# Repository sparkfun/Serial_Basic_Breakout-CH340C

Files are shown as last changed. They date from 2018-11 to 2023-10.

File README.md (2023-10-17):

SparkFun Serial Basic Breakout - CH340C
========================================

SparkFun Serial Basic Breakout - CH340C (https://www.sparkfun.com/products/15096)

[*SparkFun Serial Basic Breakout - CH340C (DEV-15096)*](https://www.sparkfun.com/products/15096)

This is a CH340C based board that converts USB to Serial. We've added USB-C to
the Serial Basic line which can provide up to 1.5 Amps of power to your next
project. USB-C is also _reversable_, which means you'll never plug in a cable
wrong again. It follows the standard Arduino pin out so this can be used to program the Pro 
and Pro Mini line of Arduinos.  It can also be used as a general serial device for debugging 
(such as with a GPS module).

Board defaults to 3.3V output and 3.3V serial signals, but cutting the trace on the underside of the board and 
soldering a jumper to 5V changes the VCC pin to output 5V and changes serial comm signals to 5V.

Repository Contents
-------------------

* **/Hardware** - Eagle design files (.brd, .sch)
* **/Production** - Production panel files (.brd)

Documentation
--------------

* **[SparkFun Fritzing repo](https://github.com/sparkfun/Fritzing_Parts/blob/main/products/15096_sparkfun_serial_basic_breakout_ch340c_usb_c.fzpz)** - Fritzing diagrams for SparkFun products.
* **[How to Install CH340 Drivers](https://www.sparkfun.com/ch340)** - Drivers if you need
* **[Hookup Guide](https://learn.sparkfun.com/tutorials/serial-basic-hookup-guide)** - Basic hookup guide

License Information
-------------------

This product is _**open source**_! 

Please review the LICENSE.md file for license information. 

If you have any questions or concerns on licensing, please contact techsupport@sparkfun.com.

Distributed as-is; no warranty is given.

- Your friends at SparkFun.

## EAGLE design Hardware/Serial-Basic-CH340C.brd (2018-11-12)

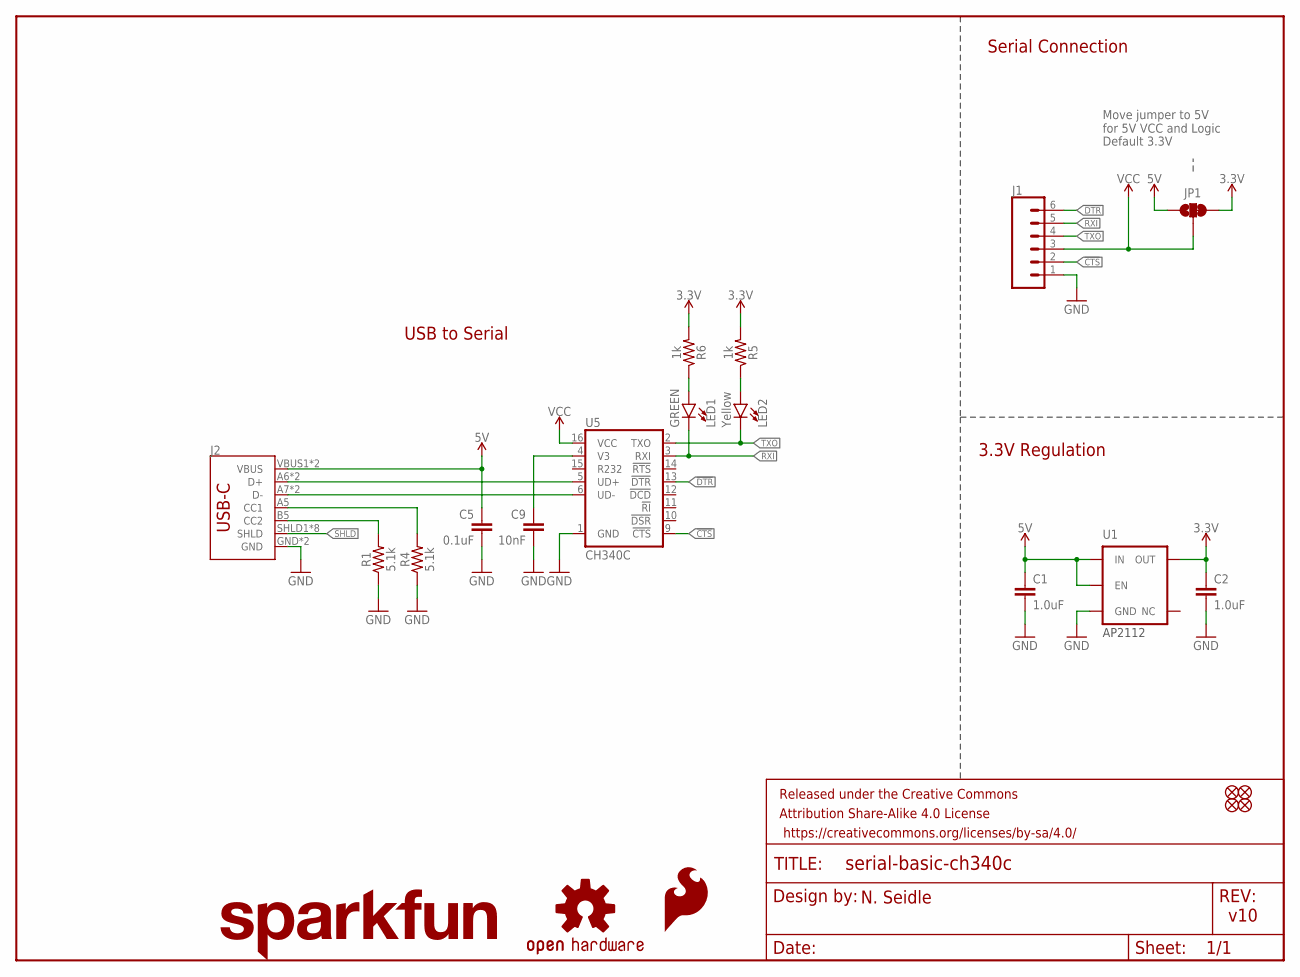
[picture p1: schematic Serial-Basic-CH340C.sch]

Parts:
C1, C2: 1.0uF; 0603
C5: 0.1uF; 0603
C9: 10nF; 0603
FRAME1: FRAME-LETTER; CREATIVE_COMMONS
J1: CONN_06SMD-FEMALE-V2; 1X06-SMD-FEMALE
J2: USB_C16PIN; USB-C-16P
JP1: JUMPER-SMT_3_1-NC_TRACE_SILK; SMT-JUMPER_3_1-NC_TRACE_SILK
JP3, JP4, JP5, JP6: FIDUCIAL1X2; FIDUCIAL-1X2
LED1: GREEN; LED-0603
LED2: Yellow; LED-0603
LOGO1: OSHW-LOGOS; OSHW-LOGO-S
LOGO2: SFE_LOGO_FLAME.1_INCH; SFE_LOGO_FLAME_.1
LOGO3: SFE_LOGO_NAME.1_INCH; SFE_LOGO_NAME_.1
R1, R4: 5.1k; 0603
R5, R6: 1k; 0603
U1: 3.3V; SOT23-5
U5: CH340C; SO016

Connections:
3.3V: C2.1, JP1.3, R5.2, R6.2, U1.5 (OUT)
5V: C1.1, C5.1, J2.VBUS1 (VBUS), J2.VBUS2 (VBUS), JP1.1, U1.1 (IN), U1.3 (EN)
!CTS: J1.2, U5.9 (!CTS)
!DTR: J1.6, U5.13 (!DTR)
CC1: J2.A5 (CC1), R4.2
CC2: J2.B5 (CC2), R1.2
D+: J2.A6 (D+), J2.B6 (D+), U5.5 (UD+)
D-: J2.A7 (D-), J2.B7 (D-), U5.6 (UD-)
GND: C1.2, C2.2, C5.2, C9.2, J1.1, J2.GND, J2.GND2 (GND), R1.1, R4.1, U1.2 (GND), U5.1 (GND)
unnamed: C9.1, U5.4 (V3)
unnamed: LED1.A, R6.1
unnamed: LED2.A, R5.1
RXI: J1.5, LED1.C, U5.3 (RXI)
SHLD: J2.SHLD1 (SHLD), J2.SHLD2 (SHLD), J2.SHLD3 (SHLD), J2.SHLD4 (SHLD), J2.SHLD5 (SHLD), J2.SHLD6 (SHLD), J2.SHLD7 (SHLD), J2.SHLD8 (SHLD)
TXO: J1.4, LED2.C, U5.2 (TXO)
VCC: J1.3, JP1.2, U5.16 (VCC)

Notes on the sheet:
Default 3.3V
v10
USB to Serial
3.3V Regulation
N. Seidle
Move jumper to 5V for 5V VCC and Logic
Serial Connection
AP2112

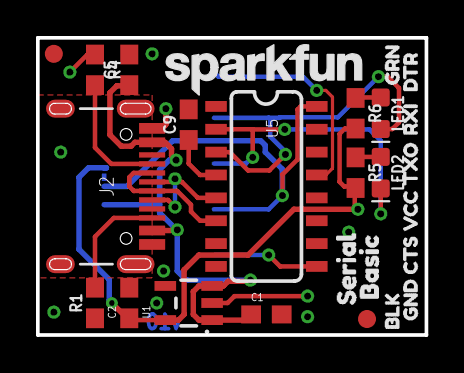
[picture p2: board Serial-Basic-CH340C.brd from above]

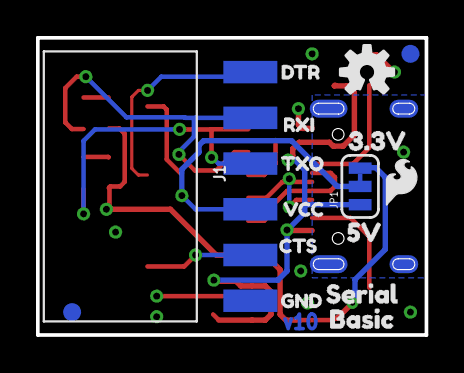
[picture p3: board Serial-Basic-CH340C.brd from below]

Board: 2 copper layers, 21.6 x 16.5 mm, 43 parts (16 on the bottom side), 16 nets.

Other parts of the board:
U$1, U$14: CTS1
U$2: 3#3V8
U$3: 5V9
U$4, U$9: SERIAL0
U$5, U$12: TXO0
U$6, U$13: VCC2
U$7, U$11: BASIC1
U$8, U$18: DTR0
U$10, U$21: RXI1
U$15, U$19: GND5
U$17: BLK6
U$20: GRN7

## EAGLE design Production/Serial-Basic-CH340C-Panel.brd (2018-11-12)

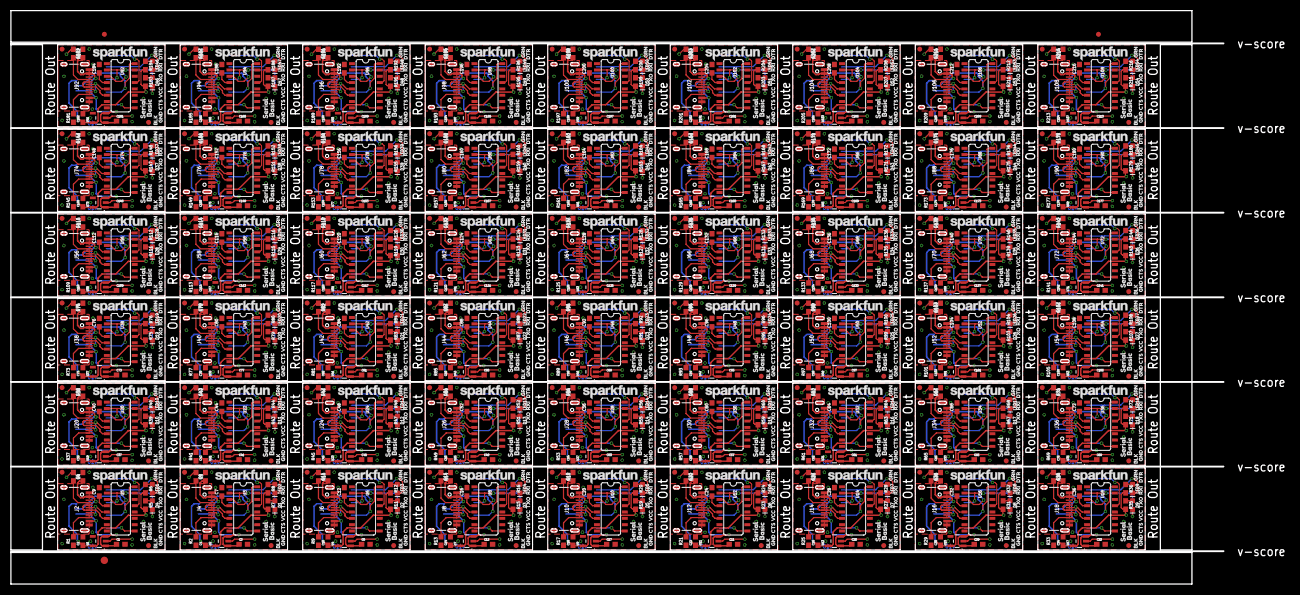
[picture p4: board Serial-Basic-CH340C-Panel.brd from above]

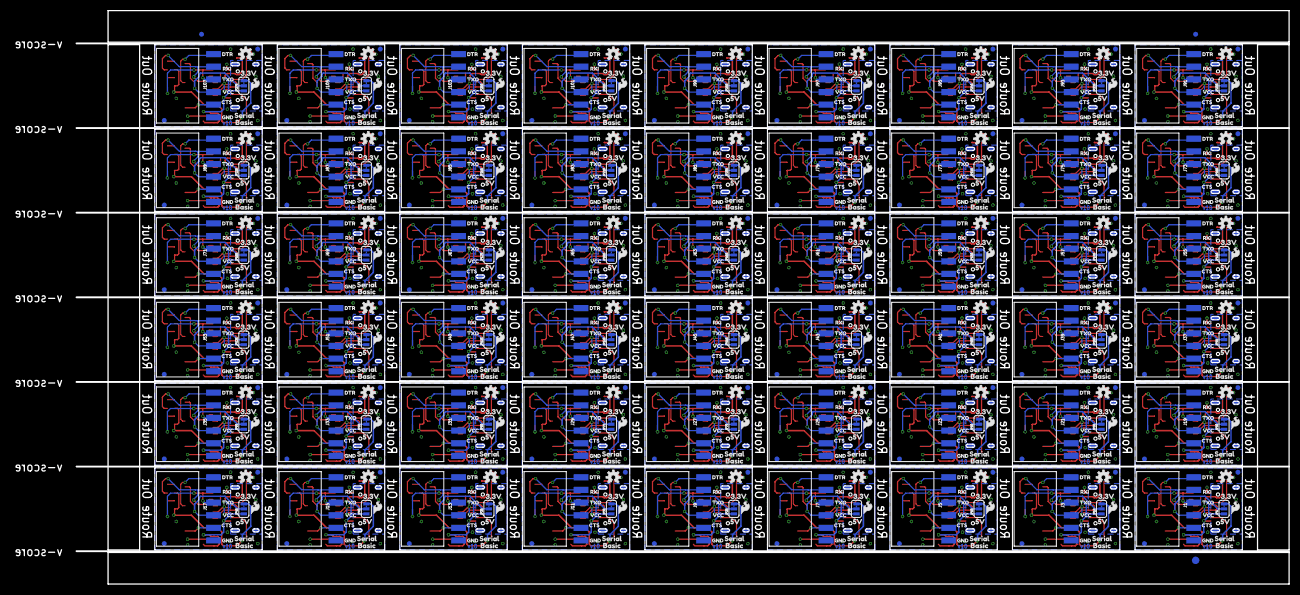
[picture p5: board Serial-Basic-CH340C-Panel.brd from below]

Board: 2 copper layers, 243.8 x 115.3 mm, 2274 parts (867 on the bottom side), 864 nets.

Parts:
C1, C2, C3, C4, C8, C10, C13, C14, C17, C18, C21, C22, C25, C26, C29, C30, C33, C34, C37, C38, C41, C42, C45, C46, C49, C50, C53, C54, C57, C58, C61, C62, C65, C66, C69, C70, C73, C74, C77, C78, C81, C82, C85, C86, C89, C90, C93, C94, C97, C98, C101, C102, C105, C106, C109, C110, C113, C114, C117, C118, C121, C122, C125, C126, C129, C130, C133, C134, C137, C138, C141, C142, C145, C146, C149, C150, C153, C154, C157, C158, C161, C162, C165, C166, C169, C170, C173, C174, C177, C178, C181, C182, C185, C186, C189, C190, C193, C194, C197, C198, C201, C202, C205, C206, C209, C210, C213, C214: 1.0uF; 0603
C5, C6, C11, C15, C19, C23, C27, C31, C35, C39, C43, C47, C51, C55, C59, C63, C67, C71, C75, C79, C83, C87, C91, C95, C99, C103, C107, C111, C115, C119, C123, C127, C131, C135, C139, C143, C147, C151, C155, C159, C163, C167, C171, C175, C179, C183, C187, C191, C195, C199, C203, C207, C211, C215: 0.1uF; 0603
C7, C9, C12, C16, C20, C24, C28, C32, C36, C40, C44, C48, C52, C56, C60, C64, C68, C72, C76, C80, C84, C88, C92, C96, C100, C104, C108, C112, C116, C120, C124, C128, C132, C136, C140, C144, C148, C152, C156, C160, C164, C168, C172, C176, C180, C184, C188, C192, C196, C200, C204, C208, C212, C216: 10nF; 0603
D1, D2, D3, D4, D5, D6, D7, D8, D9, D10, D11, D12, D13, D14, D15, D16, D17, D18, D19, D20, D21, D22, D23, D24, D25, D26, D27, D28, D29, D30, D31, D32, D33, D34, D35, D36, D37, D38, D39, D40, D41, D42, D43, D44, D45, D46, D47, D48, D49, D50, D51, D52, D53, D54: Yellow; LED-0603
E$1, E$2, E$3, E$4: FIDUCIAL-1X2
E$5, E$6: FIDUCIAL-1.5X3
J1, J3, J5, J7, J9, J11, J13, J15, J17, J19, J21, J23, J25, J27, J29, J31, J33, J35, J37, J39, J41, J43, J45, J47, J49, J51, J53, J55, J57, J59, J61, J63, J65, J67, J69, J71, J73, J75, J77, J79, J81, J83, J85, J87, J89, J91, J93, J95, J97, J99, J101, J103, J105, J107: 1X06-SMD-FEMALE
J2, J4, J6, J8, J10, J12, J14, J16, J18, J20, J22, J24, J26, J28, J30, J32, J34, J36, J38, J40, J42, J44, J46, J48, J50, J52, J54, J56, J58, J60, J62, J64, J66, J68, J70, J72, J74, J76, J78, J80, J82, J84, J86, J88, J90, J92, J94, J96, J98, J100, J102, J104, J106, J108: USB-C-16P
JP1, JP10, JP15, JP20, JP25, JP30, JP35, JP40, JP45, JP50, JP55, JP60, JP65, JP70, JP75, JP80, JP85, JP90, JP95, JP100, JP105, JP110, JP115, JP120, JP125, JP130, JP135, JP140, JP145, JP150, JP155, JP160, JP165, JP170, JP175, JP180, JP185, JP190, JP195, JP200, JP205, JP210, JP215, JP220, JP225, JP230, JP235, JP240, JP245, JP250, JP255, JP260, JP265, JP270: SMT-JUMPER_3_1-NC_TRACE_SILK
JP2, JP3, JP4, JP5, JP6, JP7, JP8, JP9, JP11, JP12, JP13, JP14, JP16, JP17, JP18, JP19, JP21, JP22, JP23, JP24, JP26, JP27, JP28, JP29, JP31, JP32, JP33, JP34, JP36, JP37, JP38, JP39, JP41, JP42, JP43, JP44, JP46, JP47, JP48, JP49, JP51, JP52, JP53, JP54, JP56, JP57, JP58, JP59, JP61, JP62, JP63, JP64, JP66, JP67, JP68, JP69, JP71, JP72, JP73, JP74, JP76, JP77, JP78, JP79, JP81, JP82, JP83, JP84, JP86, JP87, JP88, JP89, JP91, JP92, JP93, JP94, JP96, JP97, JP98, JP99, JP101, JP102, JP103, JP104, JP106, JP107, JP108, JP109, JP111, JP112, JP113, JP114, JP116, JP117, JP118, JP119, JP121, JP122, JP123, JP124, JP126, JP127, JP128, JP129, JP131, JP132, JP133, JP134, JP136, JP137, JP138, JP139, JP141, JP142, JP143, JP144, JP146, JP147, JP148, JP149, JP151, JP152, JP153, JP154, JP156, JP157, JP158, JP159, JP161, JP162, JP163, JP164, JP166, JP167, JP168, JP169, JP171, JP172, JP173, JP174, JP176, JP177, JP178, JP179, JP181, JP182, JP183, JP184, JP186, JP187, JP188, JP189, JP191, JP192, JP193, JP194, JP196, JP197, JP198, JP199, JP201, JP202, JP203, JP204, JP206, JP207, JP208, JP209, JP211, JP212, JP213, JP214, JP216, JP217, JP218, JP219, JP221, JP222, JP223, JP224, JP226, JP227, JP228, JP229, JP231, JP232, JP233, JP234, JP236, JP237, JP238, JP239, JP241, JP242, JP243, JP244, JP246, JP247, JP248, JP249, JP251, JP252, JP253, JP254, JP256, JP257, JP258, JP259, JP261, JP262, JP263, JP264, JP266, JP267, JP268, JP269: FIDUCIAL1X2; FIDUCIAL-1X2
LED1, LED2, LED3, LED4, LED5, LED6, LED7, LED8, LED9, LED10, LED11, LED12, LED13, LED14, LED15, LED16, LED17, LED18, LED19, LED20, LED21, LED22, LED23, LED24, LED25, LED26, LED27, LED28, LED29, LED30, LED31, LED32, LED33, LED34, LED35, LED36, LED37, LED38, LED39, LED40, LED41, LED42, LED43, LED44, LED45, LED46, LED47, LED48, LED49, LED50, LED51, LED52, LED53, LED54: GREEN; LED-0603
LOGO1, LOGO4, LOGO7, LOGO10, LOGO13, LOGO16, LOGO19, LOGO22, LOGO25, LOGO28, LOGO31, LOGO34, LOGO37, LOGO40, LOGO43, LOGO46, LOGO49, LOGO52, LOGO55, LOGO58, LOGO61, LOGO64, LOGO67, LOGO70, LOGO73, LOGO76, LOGO79, LOGO82, LOGO85, LOGO88, LOGO91, LOGO94, LOGO97, LOGO100, LOGO103, LOGO106, LOGO109, LOGO112, LOGO115, LOGO118, LOGO121, LOGO124, LOGO127, LOGO130, LOGO133, LOGO136, LOGO139, LOGO142, LOGO145, LOGO148, LOGO151, LOGO154, LOGO157, LOGO160: OSHW-LOGOS; OSHW-LOGO-S
LOGO2, LOGO5, LOGO8, LOGO11, LOGO14, LOGO17, LOGO20, LOGO23, LOGO26, LOGO29, LOGO32, LOGO35, LOGO38, LOGO41, LOGO44, LOGO47, LOGO50, LOGO53, LOGO56, LOGO59, LOGO62, LOGO65, LOGO68, LOGO71, LOGO74, LOGO77, LOGO80, LOGO83, LOGO86, LOGO89, LOGO92, LOGO95, LOGO98, LOGO101, LOGO104, LOGO107, LOGO110, LOGO113, LOGO116, LOGO119, LOGO122, LOGO125, LOGO128, LOGO131, LOGO134, LOGO137, LOGO140, LOGO143, LOGO146, LOGO149, LOGO152, LOGO155, LOGO158, LOGO161: SFE_LOGO_FLAME.1_INCH; SFE_LOGO_FLAME_.1
LOGO3, LOGO6, LOGO9, LOGO12, LOGO15, LOGO18, LOGO21, LOGO24, LOGO27, LOGO30, LOGO33, LOGO36, LOGO39, LOGO42, LOGO45, LOGO48, LOGO51, LOGO54, LOGO57, LOGO60, LOGO63, LOGO66, LOGO69, LOGO72, LOGO75, LOGO78, LOGO81, LOGO84, LOGO87, LOGO90, LOGO93, LOGO96, LOGO99, LOGO102, LOGO105, LOGO108, LOGO111, LOGO114, LOGO117, LOGO120, LOGO123, LOGO126, LOGO129, LOGO132, LOGO135, LOGO138, LOGO141, LOGO144, LOGO147, LOGO150, LOGO153, LOGO156, LOGO159, LOGO162: SFE_LOGO_NAME.1_INCH; SFE_LOGO_NAME_.1
R1, R2, R3, R4, R9, R10, R13, R14, R17, R18, R21, R22, R25, R26, R29, R30, R33, R34, R37, R38, R41, R42, R45, R46, R49, R50, R53, R54, R57, R58, R61, R62, R65, R66, R69, R70, R73, R74, R77, R78, R81, R82, R85, R86, R89, R90, R93, R94, R97, R98, R101, R102, R105, R106, R109, R110, R113, R114, R117, R118, R121, R122, R125, R126, R129, R130, R133, R134, R137, R138, R141, R142, R145, R146, R149, R150, R153, R154, R157, R158, R161, R162, R165, R166, R169, R170, R173, R174, R177, R178, R181, R182, R185, R186, R189, R190, R193, R194, R197, R198, R201, R202, R205, R206, R209, R210, R213, R214: 5.1k; 0603
R5, R6, R7, R8, R11, R12, R15, R16, R19, R20, R23, R24, R27, R28, R31, R32, R35, R36, R39, R40, R43, R44, R47, R48, R51, R52, R55, R56, R59, R60, R63, R64, R67, R68, R71, R72, R75, R76, R79, R80, R83, R84, R87, R88, R91, R92, R95, R96, R99, R100, R103, R104, R107, R108, R111, R112, R115, R116, R119, R120, R123, R124, R127, R128, R131, R132, R135, R136, R139, R140, R143, R144, R147, R148, R151, R152, R155, R156, R159, R160, R163, R164, R167, R168, R171, R172, R175, R176, R179, R180, R183, R184, R187, R188, R191, R192, R195, R196, R199, R200, R203, R204, R207, R208, R211, R212, R215, R216: 1k; 0603
U1, U2, U4, U7, U9, U11, U13, U15, U17, U19, U21, U23, U25, U27, U29, U31, U33, U35, U37, U39, U41, U43, U45, U47, U49, U51, U53, U55, U57, U59, U61, U63, U65, U67, U69, U71, U73, U75, U77, U79, U81, U83, U85, U87, U89, U91, U93, U95, U97, U99, U101, U103, U105, U107: AP2112-3.3V; SOT23-5
U3, U5, U6, U8, U10, U12, U14, U16, U18, U20, U22, U24, U26, U28, U30, U32, U34, U36, U38, U40, U42, U44, U46, U48, U50, U52, U54, U56, U58, U60, U62, U64, U66, U68, U70, U72, U74, U76, U78, U80, U82, U84, U86, U88, U90, U92, U94, U96, U98, U100, U102, U104, U106, U108: CH340C; SO016
U$1, U$14, U$28, U$37, U$48, U$57, U$68, U$77, U$88, U$97, U$108, U$117, U$128, U$137, U$148, U$157, U$168, U$177, U$188, U$197, U$208, U$217, U$228, U$237, U$248, U$257, U$268, U$277, U$288, U$297, U$308, U$317, U$328, U$337, U$348, U$357, U$368, U$377, U$388, U$397, U$408, U$417, U$428, U$437, U$448, U$457, U$468, U$477, U$488, U$497, U$508, U$517, U$528, U$537, U$548, U$557, U$568, U$577, U$588, U$597, U$608, U$617, U$628, U$637, U$648, U$657, U$668, U$677, U$688, U$697, U$708, U$717, U$728, U$737, U$748, U$757, U$768, U$777, U$788, U$797, U$808, U$817, U$828, U$837, U$848, U$857, U$868, U$877, U$888, U$897, U$908, U$917, U$928, U$937, U$948, U$957, U$968, U$977, U$988, U$997, U$1008, U$1017, U$1028, U$1037, U$1048, U$1057, U$1068, U$1077: CTS1
U$2, U$16, U$41, U$61, U$81, U$101, U$121, U$141, U$161, U$181, U$201, U$221, U$241, U$261, U$281, U$301, U$321, U$341, U$361, U$381, U$401, U$421, U$441, U$461, U$481, U$501, U$521, U$541, U$561, U$581, U$601, U$621, U$641, U$661, U$681, U$701, U$721, U$741, U$761, U$781, U$801, U$821, U$841, U$861, U$881, U$901, U$921, U$941, U$961, U$981, U$1001, U$1021, U$1041, U$1061: 3#3V8
U$3, U$22, U$42, U$62, U$82, U$102, U$122, U$142, U$162, U$182, U$202, U$222, U$242, U$262, U$282, U$302, U$322, U$342, U$362, U$382, U$402, U$422, U$442, U$462, U$482, U$502, U$522, U$542, U$562, U$582, U$602, U$622, U$642, U$662, U$682, U$702, U$722, U$742, U$762, U$782, U$802, U$822, U$842, U$862, U$882, U$902, U$922, U$942, U$962, U$982, U$1002, U$1022, U$1042, U$1062: 5V9
U$4, U$9, U$31, U$39, U$51, U$59, U$71, U$79, U$91, U$99, U$111, U$119, U$131, U$139, U$151, U$159, U$171, U$179, U$191, U$199, U$211, U$219, U$231, U$239, U$251, U$259, U$271, U$279, U$291, U$299, U$311, U$319, U$331, U$339, U$351, U$359, U$371, U$379, U$391, U$399, U$411, U$419, U$431, U$439, U$451, U$459, U$471, U$479, U$491, U$499, U$511, U$519, U$531, U$539, U$551, U$559, U$571, U$579, U$591, U$599, U$611, U$619, U$631, U$639, U$651, U$659, U$671, U$679, U$691, U$699, U$711, U$719, U$731, U$739, U$751, U$759, U$771, U$779, U$791, U$799, U$811, U$819, U$831, U$839, U$851, U$859, U$871, U$879, U$891, U$899, U$911, U$919, U$931, U$939, U$951, U$959, U$971, U$979, U$991, U$999, U$1011, U$1019, U$1031, U$1039, U$1051, U$1059, U$1071, U$1079: SERIAL0
U$5, U$12, U$29, U$35, U$49, U$55, U$69, U$75, U$89, U$95, U$109, U$115, U$129, U$135, U$149, U$155, U$169, U$175, U$189, U$195, U$209, U$215, U$229, U$235, U$249, U$255, U$269, U$275, U$289, U$295, U$309, U$315, U$329, U$335, U$349, U$355, U$369, U$375, U$389, U$395, U$409, U$415, U$429, U$435, U$449, U$455, U$469, U$475, U$489, U$495, U$509, U$515, U$529, U$535, U$549, U$555, U$569, U$575, U$589, U$595, U$609, U$615, U$629, U$635, U$649, U$655, U$669, U$675, U$689, U$695, U$709, U$715, U$729, U$735, U$749, U$755, U$769, U$775, U$789, U$795, U$809, U$815, U$829, U$835, U$849, U$855, U$869, U$875, U$889, U$895, U$909, U$915, U$929, U$935, U$949, U$955, U$969, U$975, U$989, U$995, U$1009, U$1015, U$1029, U$1035, U$1049, U$1055, U$1069, U$1075: TXO0
U$6, U$13, U$30, U$36, U$50, U$56, U$70, U$76, U$90, U$96, U$110, U$116, U$130, U$136, U$150, U$156, U$170, U$176, U$190, U$196, U$210, U$216, U$230, U$236, U$250, U$256, U$270, U$276, U$290, U$296, U$310, U$316, U$330, U$336, U$350, U$356, U$370, U$376, U$390, U$396, U$410, U$416, U$430, U$436, U$450, U$456, U$470, U$476, U$490, U$496, U$510, U$516, U$530, U$536, U$550, U$556, U$570, U$576, U$590, U$596, U$610, U$616, U$630, U$636, U$650, U$656, U$670, U$676, U$690, U$696, U$710, U$716, U$730, U$736, U$750, U$756, U$770, U$776, U$790, U$796, U$810, U$816, U$830, U$836, U$850, U$856, U$870, U$876, U$890, U$896, U$910, U$916, U$930, U$936, U$950, U$956, U$970, U$976, U$990, U$996, U$1010, U$1016, U$1030, U$1036, U$1050, U$1056, U$1070, U$1076: VCC2
U$7, U$11, U$32, U$40, U$52, U$60, U$72, U$80, U$92, U$100, U$112, U$120, U$132, U$140, U$152, U$160, U$172, U$180, U$192, U$200, U$212, U$220, U$232, U$240, U$252, U$260, U$272, U$280, U$292, U$300, U$312, U$320, U$332, U$340, U$352, U$360, U$372, U$380, U$392, U$400, U$412, U$420, U$432, U$440, U$452, U$460, U$472, U$480, U$492, U$500, U$512, U$520, U$532, U$540, U$552, U$560, U$572, U$580, U$592, U$600, U$612, U$620, U$632, U$640, U$652, U$660, U$672, U$680, U$692, U$700, U$712, U$720, U$732, U$740, U$752, U$760, U$772, U$780, U$792, U$800, U$812, U$820, U$832, U$840, U$852, U$860, U$872, U$880, U$892, U$900, U$912, U$920, U$932, U$940, U$952, U$960, U$972, U$980, U$992, U$1000, U$1012, U$1020, U$1032, U$1040, U$1052, U$1060, U$1072, U$1080: BASIC1
U$8, U$18, U$24, U$33, U$44, U$53, U$64, U$73, U$84, U$93, U$104, U$113, U$124, U$133, U$144, U$153, U$164, U$173, U$184, U$193, U$204, U$213, U$224, U$233, U$244, U$253, U$264, U$273, U$284, U$293, U$304, U$313, U$324, U$333, U$344, U$353, U$364, U$373, U$384, U$393, U$404, U$413, U$424, U$433, U$444, U$453, U$464, U$473, U$484, U$493, U$504, U$513, U$524, U$533, U$544, U$553, U$564, U$573, U$584, U$593, U$604, U$613, U$624, U$633, U$644, U$653, U$664, U$673, U$684, U$693, U$704, U$713, U$724, U$733, U$744, U$753, U$764, U$773, U$784, U$793, U$804, U$813, U$824, U$833, U$844, U$853, U$864, U$873, U$884, U$893, U$904, U$913, U$924, U$933, U$944, U$953, U$964, U$973, U$984, U$993, U$1004, U$1013, U$1024, U$1033, U$1044, U$1053, U$1064, U$1073: DTR0
U$10, U$21, U$27, U$34, U$47, U$54, U$67, U$74, U$87, U$94, U$107, U$114, U$127, U$134, U$147, U$154, U$167, U$174, U$187, U$194, U$207, U$214, U$227, U$234, U$247, U$254, U$267, U$274, U$287, U$294, U$307, U$314, U$327, U$334, U$347, U$354, U$367, U$374, U$387, U$394, U$407, U$414, U$427, U$434, U$447, U$454, U$467, U$474, U$487, U$494, U$507, U$514, U$527, U$534, U$547, U$554, U$567, U$574, U$587, U$594, U$607, U$614, U$627, U$634, U$647, U$654, U$667, U$674, U$687, U$694, U$707, U$714, U$727, U$734, U$747, U$754, U$767, U$774, U$787, U$794, U$807, U$814, U$827, U$834, U$847, U$854, U$867, U$874, U$887, U$894, U$907, U$914, U$927, U$934, U$947, U$954, U$967, U$974, U$987, U$994, U$1007, U$1014, U$1027, U$1034, U$1047, U$1054, U$1067, U$1074: RXI1
U$15, U$19, U$25, U$38, U$45, U$58, U$65, U$78, U$85, U$98, U$105, U$118, U$125, U$138, U$145, U$158, U$165, U$178, U$185, U$198, U$205, U$218, U$225, U$238, U$245, U$258, U$265, U$278, U$285, U$298, U$305, U$318, U$325, U$338, U$345, U$358, U$365, U$378, U$385, U$398, U$405, U$418, U$425, U$438, U$445, U$458, U$465, U$478, U$485, U$498, U$505, U$518, U$525, U$538, U$545, U$558, U$565, U$578, U$585, U$598, U$605, U$618, U$625, U$638, U$645, U$658, U$665, U$678, U$685, U$698, U$705, U$718, U$725, U$738, U$745, U$758, U$765, U$778, U$785, U$798, U$805, U$818, U$825, U$838, U$845, U$858, U$865, U$878, U$885, U$898, U$905, U$918, U$925, U$938, U$945, U$958, U$965, U$978, U$985, U$998, U$1005, U$1018, U$1025, U$1038, U$1045, U$1058, U$1065, U$1078: GND5
U$17, U$23, U$43, U$63, U$83, U$103, U$123, U$143, U$163, U$183, U$203, U$223, U$243, U$263, U$283, U$303, U$323, U$343, U$363, U$383, U$403, U$423, U$443, U$463, U$483, U$503, U$523, U$543, U$563, U$583, U$603, U$623, U$643, U$663, U$683, U$703, U$723, U$743, U$763, U$783, U$803, U$823, U$843, U$863, U$883, U$903, U$923, U$943, U$963, U$983, U$1003, U$1023, U$1043, U$1063: BLK6
U$20, U$26, U$46, U$66, U$86, U$106, U$126, U$146, U$166, U$186, U$206, U$226, U$246, U$266, U$286, U$306, U$326, U$346, U$366, U$386, U$406, U$426, U$446, U$466, U$486, U$506, U$526, U$546, U$566, U$586, U$606, U$626, U$646, U$666, U$686, U$706, U$726, U$746, U$766, U$786, U$806, U$826, U$846, U$866, U$886, U$906, U$926, U$946, U$966, U$986, U$1006, U$1026, U$1046, U$1066: GRN7

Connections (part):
3.3V: C2.1, JP1.3, R5.2, R6.2, U1.5
3.3V1: C4.1, JP10.3, R7.2, R8.2, U2.5
3.3V2: C10.1, JP15.3, R11.2, R12.2, U4.5
3.3V3: C14.1, JP20.3, R15.2, R16.2, U7.5
3.3V4: C18.1, JP25.3, R19.2, R20.2, U9.5
3.3V5: C22.1, JP30.3, R23.2, R24.2, U11.5
3.3V6: C26.1, JP35.3, R27.2, R28.2, U13.5
3.3V7: C30.1, JP40.3, R31.2, R32.2, U15.5
3.3V8: C34.1, JP45.3, R35.2, R36.2, U17.5
3.3V9: C38.1, JP50.3, R39.2, R40.2, U19.5
3.3V10: C42.1, JP55.3, R43.2, R44.2, U21.5
3.3V11: C46.1, JP60.3, R47.2, R48.2, U23.5
3.3V12: C50.1, JP65.3, R51.2, R52.2, U25.5
3.3V13: C54.1, JP70.3, R55.2, R56.2, U27.5
3.3V14: C58.1, JP75.3, R59.2, R60.2, U29.5
3.3V15: C62.1, JP80.3, R63.2, R64.2, U31.5
3.3V16: C66.1, JP85.3, R67.2, R68.2, U33.5
3.3V17: C70.1, JP90.3, R71.2, R72.2, U35.5
3.3V18: C74.1, JP95.3, R75.2, R76.2, U37.5
3.3V19: C78.1, JP100.3, R79.2, R80.2, U39.5
3.3V20: C82.1, JP105.3, R83.2, R84.2, U41.5
3.3V21: C86.1, JP110.3, R87.2, R88.2, U43.5
3.3V22: C90.1, JP115.3, R91.2, R92.2, U45.5
3.3V23: C94.1, JP120.3, R95.2, R96.2, U47.5
3.3V24: C98.1, JP125.3, R99.2, R100.2, U49.5
3.3V25: C102.1, JP130.3, R103.2, R104.2, U51.5
3.3V26: C106.1, JP135.3, R107.2, R108.2, U53.5
3.3V27: C110.1, JP140.3, R111.2, R112.2, U55.5
3.3V28: C114.1, JP145.3, R115.2, R116.2, U57.5
3.3V29: C118.1, JP150.3, R119.2, R120.2, U59.5
3.3V30: C122.1, JP155.3, R123.2, R124.2, U61.5
3.3V31: C126.1, JP160.3, R127.2, R128.2, U63.5
3.3V32: C130.1, JP165.3, R131.2, R132.2, U65.5
3.3V33: C134.1, JP170.3, R135.2, R136.2, U67.5
3.3V34: C138.1, JP175.3, R139.2, R140.2, U69.5
3.3V35: C142.1, JP180.3, R143.2, R144.2, U71.5
3.3V36: C146.1, JP185.3, R147.2, R148.2, U73.5
3.3V37: C150.1, JP190.3, R151.2, R152.2, U75.5
3.3V38: C154.1, JP195.3, R155.2, R156.2, U77.5
3.3V39: C158.1, JP200.3, R159.2, R160.2, U79.5
3.3V40: C162.1, JP205.3, R163.2, R164.2, U81.5
3.3V41: C166.1, JP210.3, R167.2, R168.2, U83.5
3.3V42: C170.1, JP215.3, R171.2, R172.2, U85.5
3.3V43: C174.1, JP220.3, R175.2, R176.2, U87.5
3.3V44: C178.1, JP225.3, R179.2, R180.2, U89.5
3.3V45: C182.1, JP230.3, R183.2, R184.2, U91.5
3.3V46: C186.1, JP235.3, R187.2, R188.2, U93.5
3.3V47: C190.1, JP240.3, R191.2, R192.2, U95.5
3.3V48: C194.1, JP245.3, R195.2, R196.2, U97.5
3.3V49: C198.1, JP250.3, R199.2, R200.2, U99.5
3.3V50: C202.1, JP255.3, R203.2, R204.2, U101.5
3.3V51: C206.1, JP260.3, R207.2, R208.2, U103.5
3.3V52: C210.1, JP265.3, R211.2, R212.2, U105.5
3.3V53: C214.1, JP270.3, R215.2, R216.2, U107.5
5V: C1.1, C5.1, J2.VBUS1, J2.VBUS2, JP1.1, U1.1, U1.3
5V1: C3.1, C6.1, J4.VBUS1, J4.VBUS2, JP10.1, U2.1, U2.3
5V2: C8.1, C11.1, J6.VBUS1, J6.VBUS2, JP15.1, U4.1, U4.3
5V3: C13.1, C15.1, J8.VBUS1, J8.VBUS2, JP20.1, U7.1, U7.3
5V4: C17.1, C19.1, J10.VBUS1, J10.VBUS2, JP25.1, U9.1, U9.3
5V5: C21.1, C23.1, J12.VBUS1, J12.VBUS2, JP30.1, U11.1, U11.3
5V6: C25.1, C27.1, J14.VBUS1, J14.VBUS2, JP35.1, U13.1, U13.3
5V7: C29.1, C31.1, J16.VBUS1, J16.VBUS2, JP40.1, U15.1, U15.3
5V8: C33.1, C35.1, J18.VBUS1, J18.VBUS2, JP45.1, U17.1, U17.3
5V9: C37.1, C39.1, J20.VBUS1, J20.VBUS2, JP50.1, U19.1, U19.3
5V10: C41.1, C43.1, J22.VBUS1, J22.VBUS2, JP55.1, U21.1, U21.3
5V11: C45.1, C47.1, J24.VBUS1, J24.VBUS2, JP60.1, U23.1, U23.3
5V12: C49.1, C51.1, J26.VBUS1, J26.VBUS2, JP65.1, U25.1, U25.3
5V13: C53.1, C55.1, J28.VBUS1, J28.VBUS2, JP70.1, U27.1, U27.3
5V14: C57.1, C59.1, J30.VBUS1, J30.VBUS2, JP75.1, U29.1, U29.3
5V15: C61.1, C63.1, J32.VBUS1, J32.VBUS2, JP80.1, U31.1, U31.3
5V16: C65.1, C67.1, J34.VBUS1, J34.VBUS2, JP85.1, U33.1, U33.3
5V17: C69.1, C71.1, J36.VBUS1, J36.VBUS2, JP90.1, U35.1, U35.3
5V18: C73.1, C75.1, J38.VBUS1, J38.VBUS2, JP95.1, U37.1, U37.3
5V19: C77.1, C79.1, J40.VBUS1, J40.VBUS2, JP100.1, U39.1, U39.3
5V20: C81.1, C83.1, J42.VBUS1, J42.VBUS2, JP105.1, U41.1, U41.3
5V21: C85.1, C87.1, J44.VBUS1, J44.VBUS2, JP110.1, U43.1, U43.3
5V22: C89.1, C91.1, J46.VBUS1, J46.VBUS2, JP115.1, U45.1, U45.3
5V23: C93.1, C95.1, J48.VBUS1, J48.VBUS2, JP120.1, U47.1, U47.3
5V24: C97.1, C99.1, J50.VBUS1, J50.VBUS2, JP125.1, U49.1, U49.3
5V25: C101.1, C103.1, J52.VBUS1, J52.VBUS2, JP130.1, U51.1, U51.3
5V26: C105.1, C107.1, J54.VBUS1, J54.VBUS2, JP135.1, U53.1, U53.3
5V27: C109.1, C111.1, J56.VBUS1, J56.VBUS2, JP140.1, U55.1, U55.3
5V28: C113.1, C115.1, J58.VBUS1, J58.VBUS2, JP145.1, U57.1, U57.3
5V29: C117.1, C119.1, J60.VBUS1, J60.VBUS2, JP150.1, U59.1, U59.3
5V30: C121.1, C123.1, J62.VBUS1, J62.VBUS2, JP155.1, U61.1, U61.3
5V31: C125.1, C127.1, J64.VBUS1, J64.VBUS2, JP160.1, U63.1, U63.3
5V32: C129.1, C131.1, J66.VBUS1, J66.VBUS2, JP165.1, U65.1, U65.3
5V33: C133.1, C135.1, J68.VBUS1, J68.VBUS2, JP170.1, U67.1, U67.3
5V34: C137.1, C139.1, J70.VBUS1, J70.VBUS2, JP175.1, U69.1, U69.3
5V35: C141.1, C143.1, J72.VBUS1, J72.VBUS2, JP180.1, U71.1, U71.3
5V36: C145.1, C147.1, J74.VBUS1, J74.VBUS2, JP185.1, U73.1, U73.3
5V37: C149.1, C151.1, J76.VBUS1, J76.VBUS2, JP190.1, U75.1, U75.3
5V38: C153.1, C155.1, J78.VBUS1, J78.VBUS2, JP195.1, U77.1, U77.3
5V39: C157.1, C159.1, J80.VBUS1, J80.VBUS2, JP200.1, U79.1, U79.3
5V40: C161.1, C163.1, J82.VBUS1, J82.VBUS2, JP205.1, U81.1, U81.3
5V41: C165.1, C167.1, J84.VBUS1, J84.VBUS2, JP210.1, U83.1, U83.3
5V42: C169.1, C171.1, J86.VBUS1, J86.VBUS2, JP215.1, U85.1, U85.3
5V43: C173.1, C175.1, J88.VBUS1, J88.VBUS2, JP220.1, U87.1, U87.3
5V44: C177.1, C179.1, J90.VBUS1, J90.VBUS2, JP225.1, U89.1, U89.3
5V45: C181.1, C183.1, J92.VBUS1, J92.VBUS2, JP230.1, U91.1, U91.3
5V46: C185.1, C187.1, J94.VBUS1, J94.VBUS2, JP235.1, U93.1, U93.3
5V47: C189.1, C191.1, J96.VBUS1, J96.VBUS2, JP240.1, U95.1, U95.3
5V48: C193.1, C195.1, J98.VBUS1, J98.VBUS2, JP245.1, U97.1, U97.3
5V49: C197.1, C199.1, J100.VBUS1, J100.VBUS2, JP250.1, U99.1, U99.3
5V50: C201.1, C203.1, J102.VBUS1, J102.VBUS2, JP255.1, U101.1, U101.3
5V51: C205.1, C207.1, J104.VBUS1, J104.VBUS2, JP260.1, U103.1, U103.3
5V52: C209.1, C211.1, J106.VBUS1, J106.VBUS2, JP265.1, U105.1, U105.3
5V53: C213.1, C215.1, J108.VBUS1, J108.VBUS2, JP270.1, U107.1, U107.3
!CTS: J1.2, U5.9
!CTS1: J3.2, U3.9
!CTS2: J5.2, U6.9
!CTS3: J7.2, U8.9
!CTS4: J9.2, U10.9
!CTS5: J11.2, U12.9
!CTS6: J13.2, U14.9
!CTS7: J15.2, U16.9
!CTS8: J17.2, U18.9
!CTS9: J19.2, U20.9
!CTS10: J21.2, U22.9
!CTS11: J23.2, U24.9
!CTS12: J25.2, U26.9
!CTS13: J27.2, U28.9
!CTS14: J29.2, U30.9
!CTS15: J31.2, U32.9
!CTS16: J33.2, U34.9
!CTS17: J35.2, U36.9
!CTS18: J37.2, U38.9
!CTS19: J39.2, U40.9
!CTS20: J41.2, U42.9
!CTS21: J43.2, U44.9
!CTS22: J45.2, U46.9
!CTS23: J47.2, U48.9
!CTS24: J49.2, U50.9
!CTS25: J51.2, U52.9
!CTS26: J53.2, U54.9
!CTS27: J55.2, U56.9
!CTS28: J57.2, U58.9
!CTS29: J59.2, U60.9
!CTS30: J61.2, U62.9
!CTS31: J63.2, U64.9
!CTS32: J65.2, U66.9
!CTS33: J67.2, U68.9
!CTS34: J69.2, U70.9
!CTS35: J71.2, U72.9
!CTS36: J73.2, U74.9
!CTS37: J75.2, U76.9
!CTS38: J77.2, U78.9
!CTS39: J79.2, U80.9
!CTS40: J81.2, U82.9
!CTS41: J83.2, U84.9
!CTS42: J85.2, U86.9
!CTS43: J87.2, U88.9
!CTS44: J89.2, U90.9
!CTS45: J91.2, U92.9
!CTS46: J93.2, U94.9
!CTS47: J95.2, U96.9
!CTS48: J97.2, U98.9
!CTS49: J99.2, U100.9
!CTS50: J101.2, U102.9
!CTS51: J103.2, U104.9
!CTS52: J105.2, U106.9
!CTS53: J107.2, U108.9
!DTR: J1.6, U5.13
!DTR1: J3.6, U3.13
!DTR2: J5.6, U6.13
!DTR3: J7.6, U8.13
!DTR4: J9.6, U10.13
!DTR5: J11.6, U12.13
!DTR6: J13.6, U14.13
!DTR7: J15.6, U16.13
!DTR8: J17.6, U18.13
!DTR9: J19.6, U20.13
!DTR10: J21.6, U22.13
!DTR11: J23.6, U24.13
!DTR12: J25.6, U26.13
!DTR13: J27.6, U28.13
!DTR14: J29.6, U30.13
!DTR15: J31.6, U32.13
!DTR16: J33.6, U34.13
!DTR17: J35.6, U36.13
!DTR18: J37.6, U38.13
!DTR19: J39.6, U40.13
!DTR20: J41.6, U42.13
!DTR21: J43.6, U44.13
!DTR22: J45.6, U46.13
!DTR23: J47.6, U48.13
!DTR24: J49.6, U50.13
!DTR25: J51.6, U52.13
!DTR26: J53.6, U54.13
!DTR27: J55.6, U56.13
!DTR28: J57.6, U58.13
!DTR29: J59.6, U60.13
!DTR30: J61.6, U62.13
!DTR31: J63.6, U64.13
!DTR32: J65.6, U66.13
!DTR33: J67.6, U68.13
!DTR34: J69.6, U70.13
!DTR35: J71.6, U72.13
!DTR36: J73.6, U74.13
!DTR37: J75.6, U76.13
!DTR38: J77.6, U78.13
!DTR39: J79.6, U80.13
!DTR40: J81.6, U82.13
!DTR41: J83.6, U84.13
!DTR42: J85.6, U86.13
!DTR43: J87.6, U88.13
!DTR44: J89.6, U90.13
!DTR45: J91.6, U92.13
!DTR46: J93.6, U94.13
!DTR47: J95.6, U96.13
!DTR48: J97.6, U98.13
!DTR49: J99.6, U100.13
!DTR50: J101.6, U102.13
!DTR51: J103.6, U104.13
!DTR52: J105.6, U106.13
!DTR53: J107.6, U108.13
CC1: J2.A5, R4.2
CC2: J2.B5, R1.2
CC3: J4.A5, R3.2
CC4: J4.B5, R2.2
CC5: J6.A5, R10.2
CC6: J6.B5, R9.2
CC7: J8.A5, R14.2
CC8: J8.B5, R13.2
CC9: J10.A5, R18.2
CC10: J10.B5, R17.2
CC11: J12.A5, R22.2
CC12: J12.B5, R21.2
CC13: J14.A5, R26.2
CC14: J14.B5, R25.2
CC15: J16.A5, R30.2
CC16: J16.B5, R29.2
CC17: J18.A5, R34.2
CC18: J18.B5, R33.2
CC19: J20.A5, R38.2
CC20: J20.B5, R37.2
CC21: J22.A5, R42.2
CC22: J22.B5, R41.2
CC23: J24.A5, R46.2
CC24: J24.B5, R45.2
CC25: J26.A5, R50.2
CC26: J26.B5, R49.2
CC27: J28.A5, R54.2
CC28: J28.B5, R53.2
CC29: J30.A5, R58.2
CC30: J30.B5, R57.2
CC31: J32.A5, R62.2
CC32: J32.B5, R61.2
CC33: J34.A5, R66.2
CC34: J34.B5, R65.2
CC35: J36.A5, R70.2
CC36: J36.B5, R69.2
CC37: J38.A5, R74.2
CC38: J38.B5, R73.2
CC39: J40.A5, R78.2
CC40: J40.B5, R77.2
CC41: J42.A5, R82.2
CC42: J42.B5, R81.2
CC43: J44.A5, R86.2
CC44: J44.B5, R85.2
CC45: J46.A5, R90.2
CC46: J46.B5, R89.2
CC47: J48.A5, R94.2
CC48: J48.B5, R93.2
CC49: J50.A5, R98.2
CC50: J50.B5, R97.2
CC51: J52.A5, R102.2
CC52: J52.B5, R101.2
CC53: J54.A5, R106.2
CC54: J54.B5, R105.2
CC55: J56.A5, R110.2
CC56: J56.B5, R109.2
CC57: J58.A5, R114.2
CC58: J58.B5, R113.2
CC59: J60.A5, R118.2
CC60: J60.B5, R117.2
CC61: J62.A5, R122.2
CC62: J62.B5, R121.2
CC63: J64.A5, R126.2
CC64: J64.B5, R125.2
CC65: J66.A5, R130.2
CC66: J66.B5, R129.2
CC67: J68.A5, R134.2
CC68: J68.B5, R133.2
CC69: J70.A5, R138.2
CC70: J70.B5, R137.2
CC71: J72.A5, R142.2
CC72: J72.B5, R141.2
CC73: J74.A5, R146.2
CC74: J74.B5, R145.2
CC75: J76.A5, R150.2
CC76: J76.B5, R149.2
CC77: J78.A5, R154.2
CC78: J78.B5, R153.2
CC79: J80.A5, R158.2
CC80: J80.B5, R157.2
CC81: J82.A5, R162.2
CC82: J82.B5, R161.2
CC83: J84.A5, R166.2
CC84: J84.B5, R165.2
CC85: J86.A5, R170.2
CC86: J86.B5, R169.2
CC87: J88.A5, R174.2
CC88: J88.B5, R173.2
CC89: J90.A5, R178.2
CC90: J90.B5, R177.2
CC91: J92.A5, R182.2
CC92: J92.B5, R181.2
CC93: J94.A5, R186.2
CC94: J94.B5, R185.2
CC95: J96.A5, R190.2
CC96: J96.B5, R189.2
CC97: J98.A5, R194.2
CC98: J98.B5, R193.2
CC99: J100.A5, R198.2
CC100: J100.B5, R197.2
CC101: J102.A5, R202.2
CC102: J102.B5, R201.2
CC103: J104.A5, R206.2
CC104: J104.B5, R205.2
CC105: J106.A5, R210.2
CC106: J106.B5, R209.2
CC107: J108.A5, R214.2
CC108: J108.B5, R213.2
D+: J2.A6, J2.B6, U5.5
D+1: J4.A6, J4.B6, U3.5
D+2: J6.A6, J6.B6, U6.5
D+3: J8.A6, J8.B6, U8.5
D+4: J10.A6, J10.B6, U10.5
D+5: J12.A6, J12.B6, U12.5
D+6: J14.A6, J14.B6, U14.5
D+7: J16.A6, J16.B6, U16.5
D+8: J18.A6, J18.B6, U18.5
D+9: J20.A6, J20.B6, U20.5
D+10: J22.A6, J22.B6, U22.5
D+11: J24.A6, J24.B6, U24.5
D+12: J26.A6, J26.B6, U26.5
D+13: J28.A6, J28.B6, U28.5
D+14: J30.A6, J30.B6, U30.5
D+15: J32.A6, J32.B6, U32.5
D+16: J34.A6, J34.B6, U34.5
D+17: J36.A6, J36.B6, U36.5
D+18: J38.A6, J38.B6, U38.5
D+19: J40.A6, J40.B6, U40.5
D+20: J42.A6, J42.B6, U42.5
D+21: J44.A6, J44.B6, U44.5
D+22: J46.A6, J46.B6, U46.5
D+23: J48.A6, J48.B6, U48.5
D+24: J50.A6, J50.B6, U50.5
D+25: J52.A6, J52.B6, U52.5
D+26: J54.A6, J54.B6, U54.5
D+27: J56.A6, J56.B6, U56.5
D+28: J58.A6, J58.B6, U58.5
D+29: J60.A6, J60.B6, U60.5
D+30: J62.A6, J62.B6, U62.5
D+31: J64.A6, J64.B6, U64.5
D+32: J66.A6, J66.B6, U66.5
D+33: J68.A6, J68.B6, U68.5
D+34: J70.A6, J70.B6, U70.5
D+35: J72.A6, J72.B6, U72.5
D+36: J74.A6, J74.B6, U74.5
D+37: J76.A6, J76.B6, U76.5
D+38: J78.A6, J78.B6, U78.5
D+39: J80.A6, J80.B6, U80.5
D+40: J82.A6, J82.B6, U82.5
D+41: J84.A6, J84.B6, U84.5
D+42: J86.A6, J86.B6, U86.5
D+43: J88.A6, J88.B6, U88.5
D+44: J90.A6, J90.B6, U90.5
D+45: J92.A6, J92.B6, U92.5
D+46: J94.A6, J94.B6, U94.5
D+47: J96.A6, J96.B6, U96.5
D+48: J98.A6, J98.B6, U98.5
D+49: J100.A6, J100.B6, U100.5
D+50: J102.A6, J102.B6, U102.5
D+51: J104.A6, J104.B6, U104.5
D+52: J106.A6, J106.B6, U106.5
D+53: J108.A6, J108.B6, U108.5
D-: J2.A7, J2.B7, U5.6
D-1: J4.A7, J4.B7, U3.6
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

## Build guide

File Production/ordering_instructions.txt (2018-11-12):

panel size, 238x116mm
PCB thickness, 1.6mm
number of layers, 2
soldermask color, Red
silkscreen color, White
oz copper, 1oz
finish, HASL lead free
stencils, top+bottom
pcs per panel, 54

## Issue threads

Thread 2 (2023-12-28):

USB  not detected on Raspberry pi 3B+

kavyadevd, 2023-12-28:
I have connected the Serial_Basic_Breakout-CH340C to my raspberry pi via an externally powered USB hub following is the output of dmesg -w

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

The device is not detected /dev/ttyyUSB*  or lsusb

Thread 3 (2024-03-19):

CH340C Implementation with 5V and 3V3 Support

zwu513, 2024-03-19:
The CH340C datasheet says to connect V3 to VCC when running in 3V3 mode, but the CH340C breakout board with USB C does not implement this.

Product: https://cdn.sparkfun.com/assets/5/2/5/4/2/Serial-Basic-CH340C-and-USBC.pdf
Datasheet: https://cdn.sparkfun.com/assets/5/0/a/8/5/CH340DS1.PDF
Section 5.1
CH340 supports 5V and 3.3V power supply. When using 5V power supply, the VCC pin connects 5V power and the V3 pin should connect with a 0.1uF decoupling capacitor. When using 3.3V power supply, V3 should connect with VCC, both powered with 3.3V power supply, and the other circuit voltage which connected with CH340 cannot exceed 3.3V

Closed 2024-03-19.

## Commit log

2018-11-12 Updating libraries, tidied up schematic, deleted unneccessary files, adding readme outline
    [Serial-Basic-CH340C-Panel.GBL, Serial-Basic-CH340C-Panel.GBO, Serial-Basic-CH340C-Panel.GBP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]
2018-12-06 Add Hardware Folder Path
    [Serial-Basic-CH340C.brd, Serial-Basic-CH340C.sch]

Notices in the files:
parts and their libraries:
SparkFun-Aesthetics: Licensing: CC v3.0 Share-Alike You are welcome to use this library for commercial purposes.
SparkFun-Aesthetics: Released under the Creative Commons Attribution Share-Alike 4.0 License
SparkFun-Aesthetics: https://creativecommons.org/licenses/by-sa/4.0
